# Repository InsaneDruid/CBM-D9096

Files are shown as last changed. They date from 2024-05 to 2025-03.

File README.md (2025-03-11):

# CBM D9096 - a PetSD+ variant
Inspired by the work of Steve J. Gray and his cbmSD-mini, the CBM D9096 is a cost- and feature-reduced version of Nils Eiler's PetSD+ board, designed specifically for headless operation in an external enclosure, connected with a true GPIB cable, similar to a D9060 or D9090.

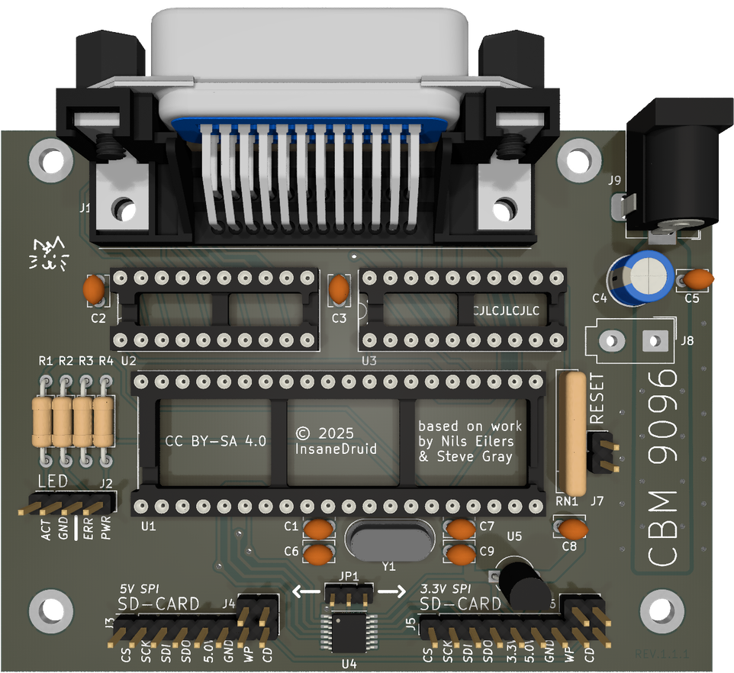
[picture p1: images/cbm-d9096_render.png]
CBM 9096 render


[Schematic](https://github.com/InsaneDruid/cbm-d9096/blob/main/cbm-d9096/cbm-d9096.pdf "Schematic")  

[Bill of Materials](https://htmlpreview.github.io/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 "Bill of Materials")

## The features
A 24-pin Centronics IEEE488/GBIP connector allows the CBM D9096 to be placed anywhere in the IEEE488 chain. This also eliminates the need for a second connector, as the IEEE488 connectors are designed to be stackable.
The SD-Card interface, the status LED and the RESET Button are implemented as pinheaders, so that the main PCB with the GBIB plug and power port can be spaced away from the parts the user needs to interact with, giving flexibility in the design of a case. Additionally, the option to use a Molex Mini Fit Jr Power Plug for connecting to an internal power supply has been implemented.

## The features that got removed
The display with its display controller, the clock, the clock battery, the buttons for interfacing with the display, and the IEC connector have been removed. The circuitry to support SD cards (mainly the 3.3 V power regulator) has also been moved to the readily available card modules. This allows the use of SD and MicroSD modules and the aforementioned flexibility in positioning these modules in a housing.

## The SD card adapters - 1.1.0 adding more options
The board now features two headers to attach readily available SD card and Micro SD card modules.
The one marked *5V SPI SD-CARD* (J3) is operating at 5 volts! The card modules attached here  MUST have appropriate level shifters installed.
Tis applies to nearly all readily available Micro SD card modules, but only some older SD card modules.
Tested and working boards are: *DEBO MICROSD 2* and *C-Control Pro Nr. 197220*
Boards that just use a voltage regulator and some passive resistors do NOT work on this header!

To use the 5V SPI SD-CARD header, JP1 needs to be set to position 2-3 (leftwards)

The one marked *3.3V SPI SD-CARD* (J5) is operating at 3.3 volts using a TXU0304 SPI level shifter and a 3.3V regulator.The card modules attached here don't need (and should *not* have!) their own level shifters.
This applies to nearly all readily available full size SD card modules. Note: this port supplies 3.3V OR 5V to the card module. Select the appropriate pin depending on the card module to connect. 

To use the 3.3V SPI SD-CARD header, JP1 needs to be set to position 1-2 (rightwards)

*Attention!* you CANNOT use two SD card modules at the same time!

## The *card detect* and *write protect* signals
Both SD card headers J3 & J5 have ground pin headers available behind the pins for the card detect ("CD") and write protect ("WP) signals (marked J4 & J6). If the attached card module doesn't provide these signals, for example all Micro SD modules, connect a 2.54mm jumper between the CD and or WP pins of J3/J5 and the associated pin of J4/J6 to permanently tie these signals to ground (permanently enable them).

## The Firmware
Andy Grady has provided a customized [firmware](https://github.com/InsaneDruid/cbm-d9096/blob/main/firmware/cbm-d9096.bin "cbm-d9096.bin") in which the button input is completely deactivated, so that the use of a voltage divider and filtered analog voltage is no longer necessary and with V1.1.0 these supporting parts are omitted. 

### Firmware installation
* Flash the [bootloader](https://github.com/InsaneDruid/cbm-d9096/blob/main/firmware/new-bootloader-for-16-MHz-petSD-plus.hex "new-bootloader-for-16-MHz-petSD-plus.hex") file to the Atmega. 
    * Set the fuse bits to Low: F7, High: D2, Extended: FC
        * low: CKSEL3=low
        * high: SPIEN=0, EESAVE=0, BOOTSZ1=0, BOOTRST=0
        * extended: BODLEVEL1=0, BODLEVEL0=0
* Install the Atmega in the board.
* Copy the [firmware](https://github.com/InsaneDruid/cbm-d9096/blob/main/firmware/cbm-d9096.bin "cbm-d9096.bin") to a FAT16 or FAT32 formatted SD-card.
* Insert the prepared card and turn on the d9096.
* On startup, the bootloader will program the firmware to the Atmega.
    * The file name is not important - the bootloader checks for a hardware tag and version number in the file.
    * During the flash operation the busy LED flickers rapidly.
    * If a valid firmware is not found, the boot loader will flash the error LED for two seconds and try to find a valid file once more.

## The LED options
The board is designed to be configured for a 2 LED or 3 LED setup:

### 2 LED variant
In the 2 LED variant power and error are combined in a *bidirectional* dual-color led (NOT common cathode or common anode!), reminiscent of how the CBM drives did. Activity is shown on a standard LED.

* install a jumper wire in place of R2
* connect a bidirectional LED between pins 3 (error) and 4 (power) of J2
* connect a standard LED between pins 1(activity) and 2 (gnd) of J2

### 3 LED variant
In the 3 LED variant power and error as well as activity are displayed with independent LED.

* don't install R4 (leave open)
* install a 330 Ohm resistor in R1, R2, R3
* connect power LED between pins 4 (power) and 2 (GND) of J2
* connect error LED between pins 3 (error) and 2 (GND) of J2
* connect activity LED between pins 1 (activity) and 2 (GND) of J2

## The printable housing option
To adapt the cheaply available Bahar enclosue 150*140*70mm project box, 3d printable parts are available.

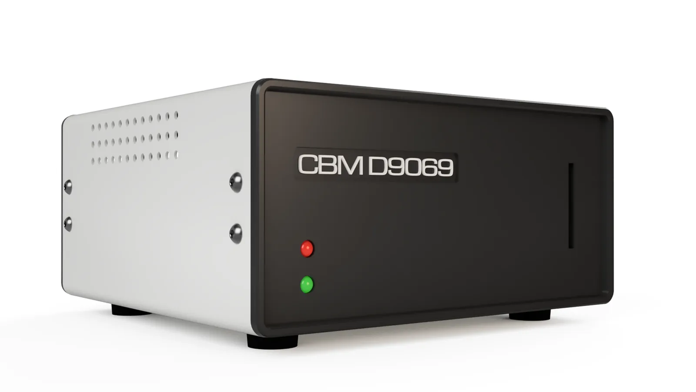
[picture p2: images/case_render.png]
Case render

[Printable parts on printables.com](https://www.printables.com/model/878141-cbm-d9069/ "Printable parts on printables.com")  

## The License
This work is licensed under a Creative Commons Attribution-ShareAlike 4.0 International License.  
See https://creativecommons.org/licenses/by-sa/4.0/.

## The Credits
This work would not have been possible without the work of Nils Eilers and his wonderful PetSD+. In addition, Steve J. Gray had the idea of a similar cost- and feature-reduced version of the PetSD+ when he designed his cbmSD-mini, which uses board-edge connectors and is designed to connect directly to the PETs board and case. This work inspired the CBM D9096.

Special thanks also go to Andy Grady for the customized firmware.

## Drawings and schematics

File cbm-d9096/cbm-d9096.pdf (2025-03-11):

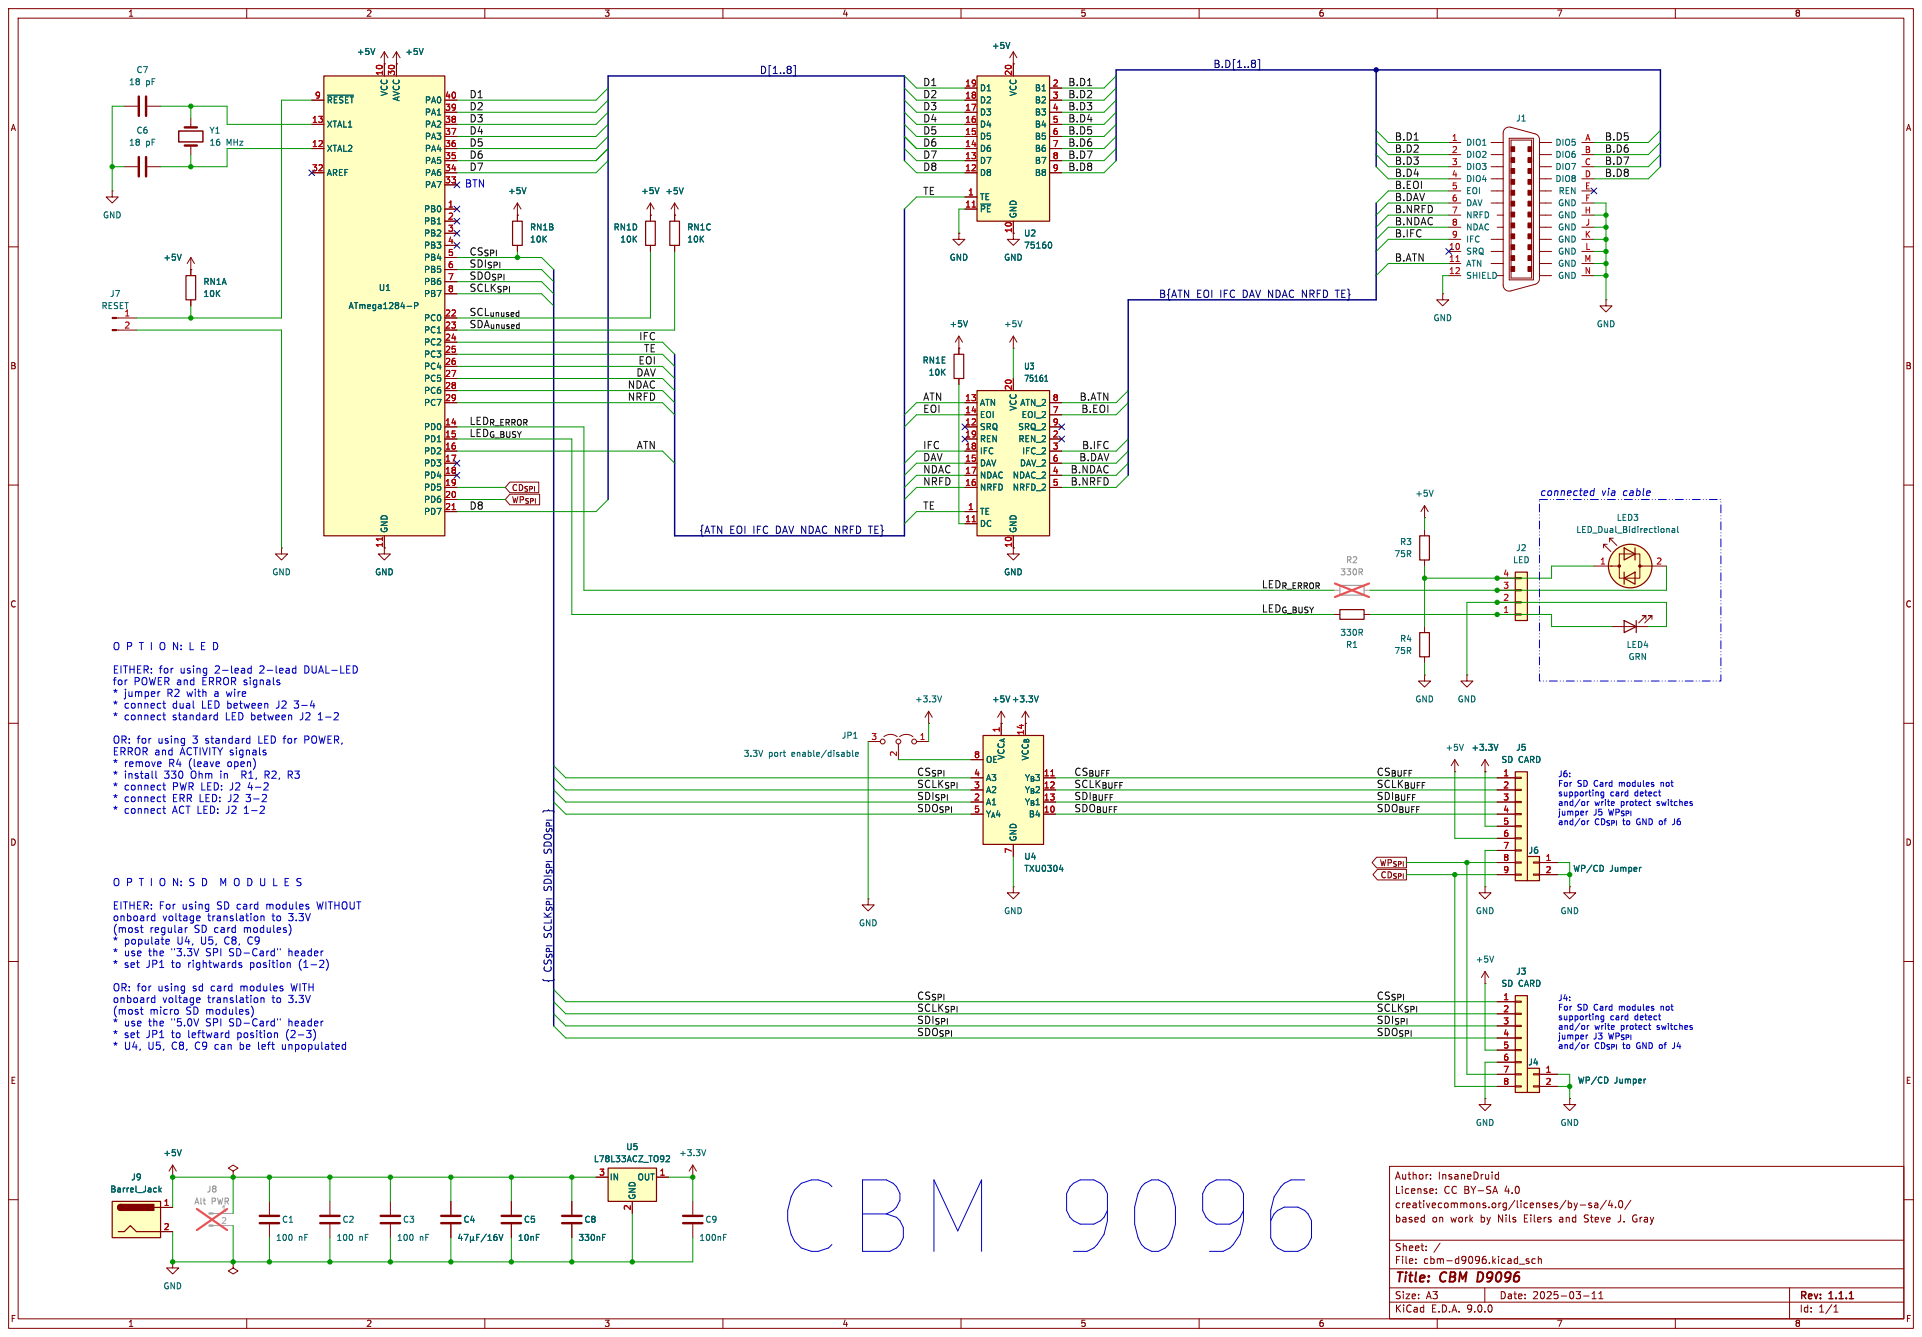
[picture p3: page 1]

DIO1 1 DIO2 2 DIO3 3 DIO4 4 EOI 5 DAV 6 NRFD 7 NDAC 8

DIO8 D
REN E GND F GND H GND J GND K GND L GND M

B{ATN EOI IFC DAV NDAC NRFD TE}

75161 ATN 13 EOI 14 SRQ 12 REN 19
ATN 13 EOI 14 SRQ 12 REN 19

{ATN EOI IFC DAV NDAC NRFD TE}

for POWER and ERROR signals
* jumper R2 with a wire
* connect dual LED between J2 3-4

ERROR and ACTIVITY signals

{ CS_{SPI}SCLK_{SPI}SDI_{SPI}SDO_{SPI} } CS_{SPI}

EITHER: For using SD card modules WITHOUT

OR: for using sd card modules WITH

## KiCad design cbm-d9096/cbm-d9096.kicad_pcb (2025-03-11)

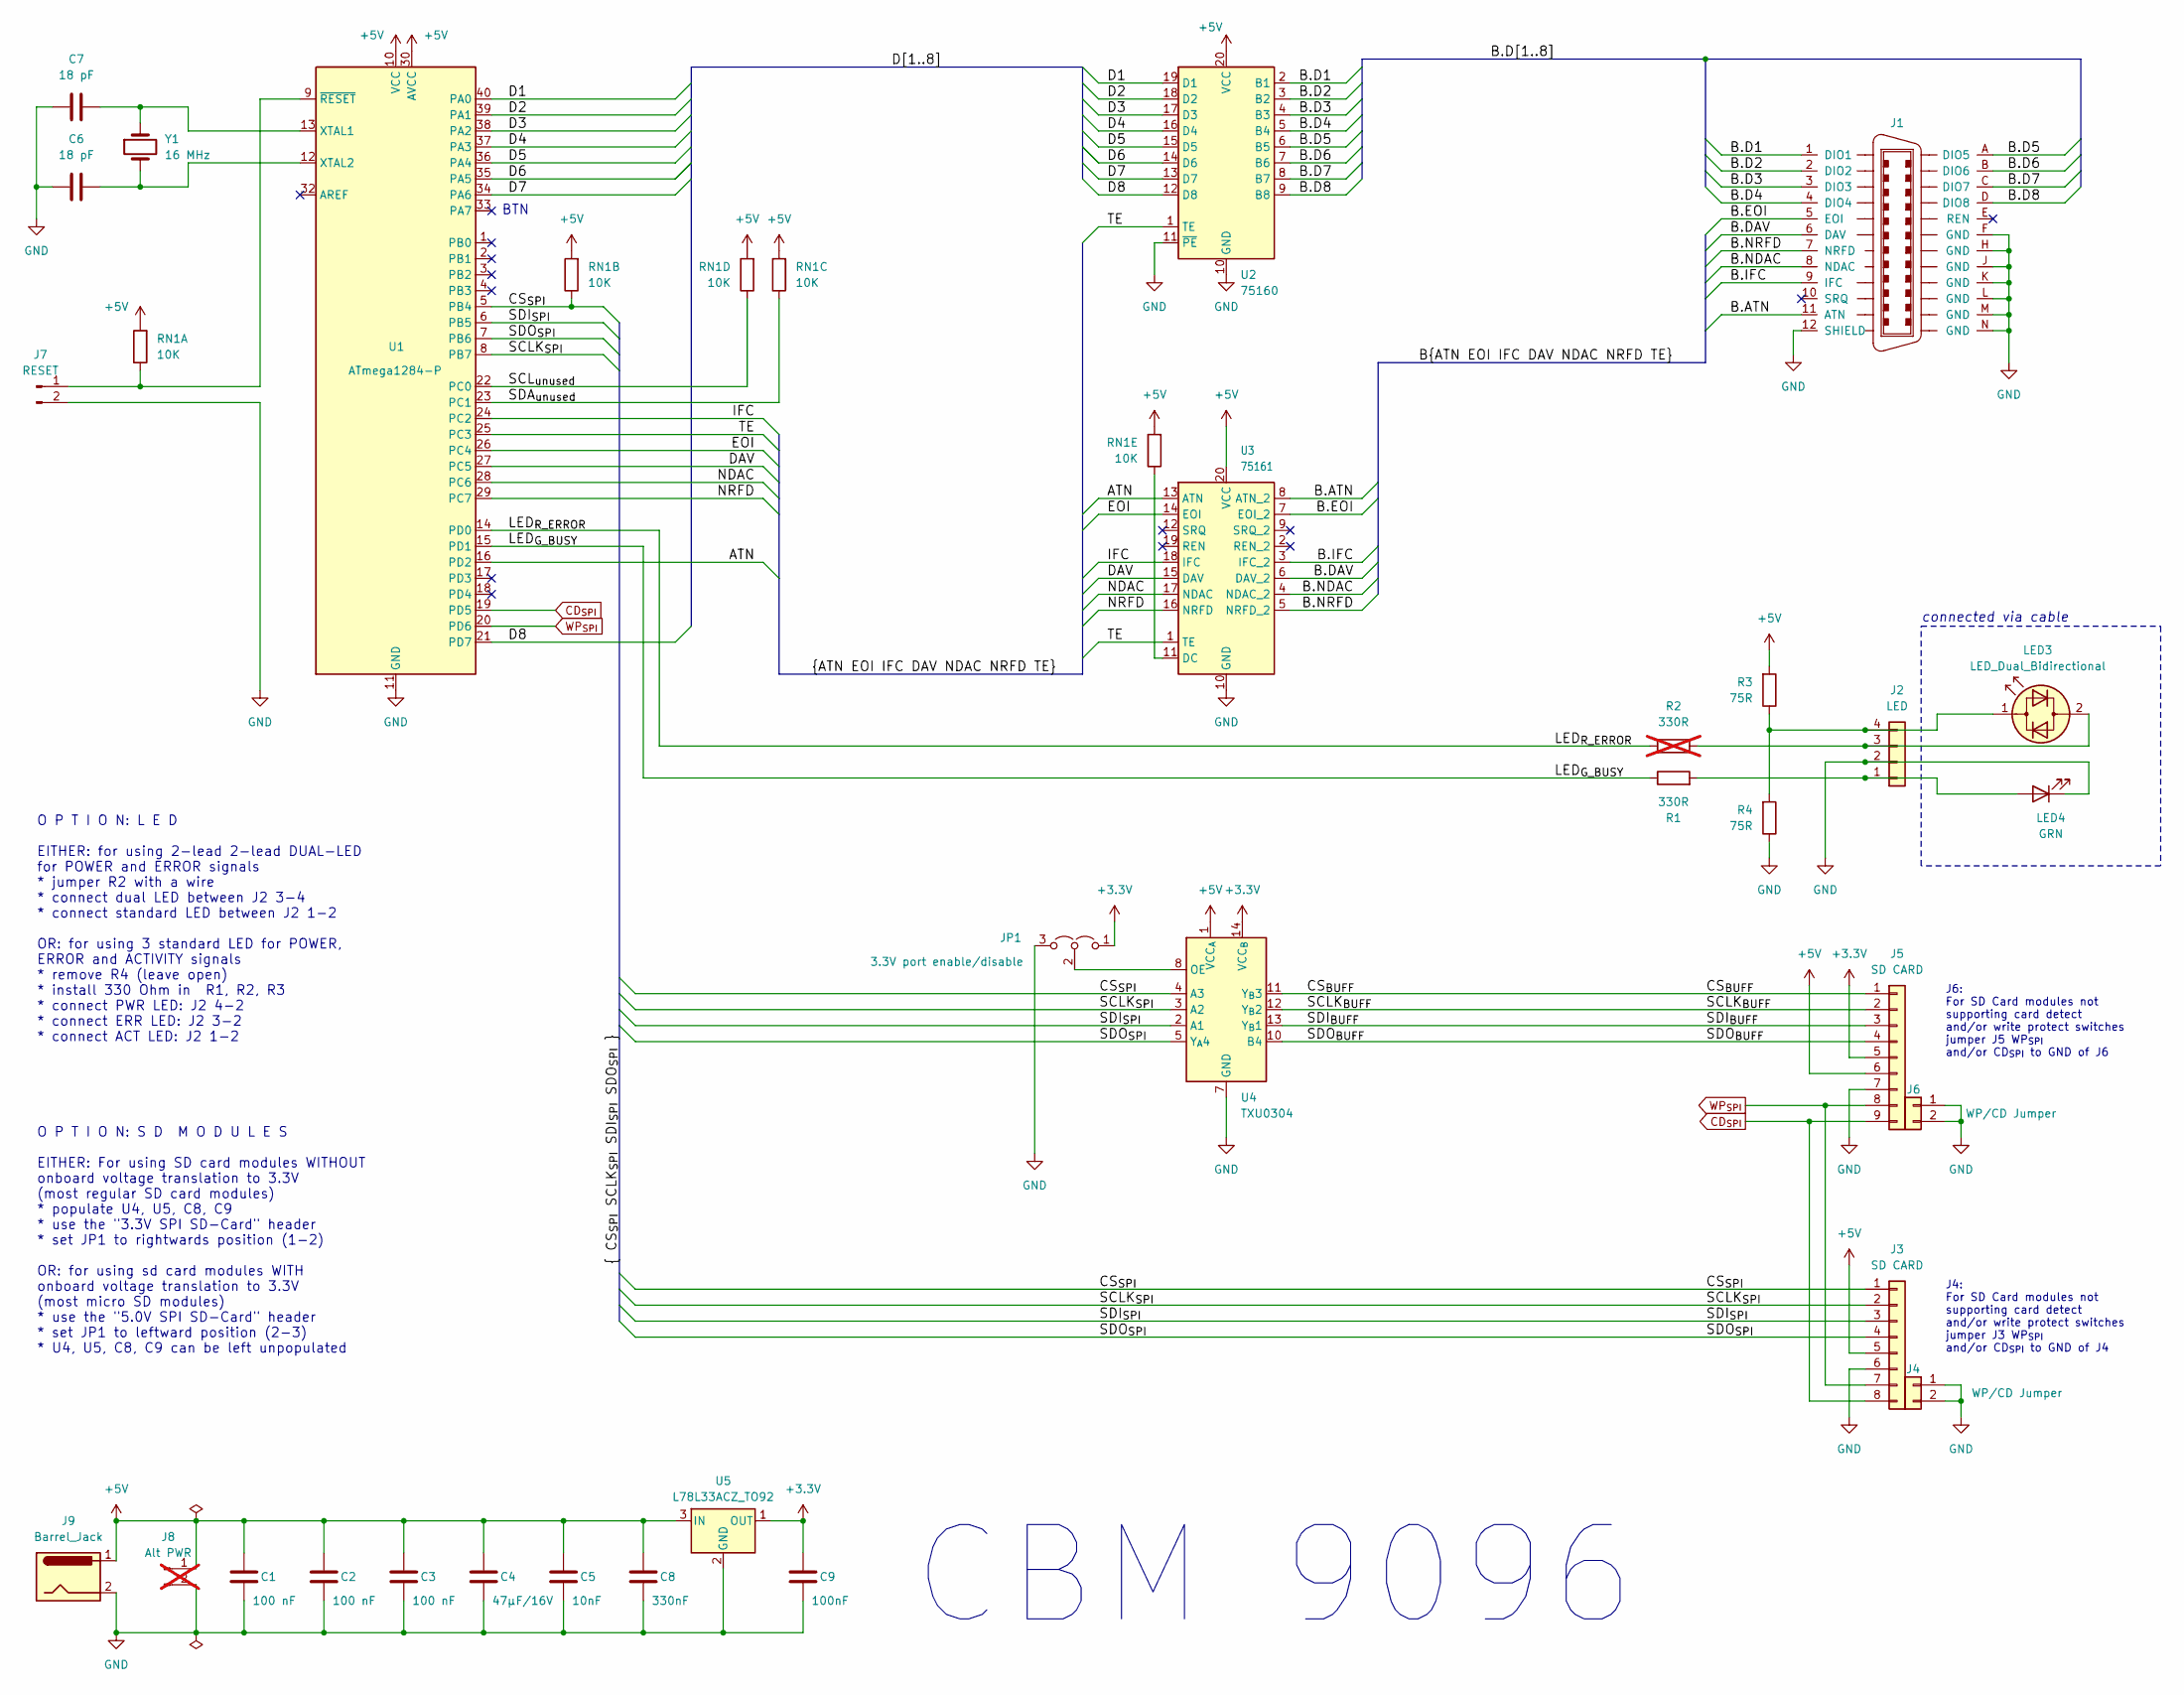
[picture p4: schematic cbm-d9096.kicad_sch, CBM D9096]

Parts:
C1, C2, C3: 100 nF; C_Disc_D3.8mm_W2.6mm_P2.50mm
C4: 47µF/16V; CP_Radial_D6.3mm_P2.50mm
C5: 10nF; C_Disc_D3.8mm_W2.6mm_P2.50mm
C6, C7: 18 pF; C_Disc_D3.8mm_W2.6mm_P2.50mm
C8: 330nF; C_Disc_D3.8mm_W2.6mm_P2.50mm
C9: 100nF; C_Disc_D3.8mm_W2.6mm_P2.50mm
J1: IEEE488 Header; centronix-24-female
J2: LED; PinHeader_1x04_P2.54mm_Vertical
J3: SD CARD; PinHeader_1x08_P2.54mm_Vertical
J4, J6: WP/CD Jumper; PinHeader_1x02_P2.54mm_Vertical
J5: SD CARD; PinHeader_1x09_P2.54mm_Vertical
J7: RESET; PinHeader_1x02_P2.54mm_Vertical
J8: Alt PWR; Molex_Mini-Fit_Jr_5566-02A_2x01_P4.20mm_Vertical; not fitted
J9: Barrel_Jack; BarrelJack_Horizontal
JP1: 3.3V port enable/disable; PinHeader_1x03_P2.00mm_Vertical
LED3: LED_Dual_Bidirectional
LED4: GRN; LED_D3.0mm_Clear
R1: 330R; R_Axial_DIN0207_L6.3mm_D2.5mm_P10.16mm_Horizontal
R2: 330R; R_Axial_DIN0207_L6.3mm_D2.5mm_P10.16mm_Horizontal; not fitted
R3, R4: 75R; R_Axial_DIN0207_L6.3mm_D2.5mm_P10.16mm_Horizontal
RN1: 10K; R_Array_SIP6
U1: ATmega1284-P; DIP-40_W15.24mm_Socket
U2: 75160; DIP-20_W7.62mm_Socket
U3: 75161; DIP-20_W7.62mm_Socket
U4: TXU0304; TSSOP-14_4.4x5mm_P0.65mm
U5: L78L33ACZ_TO92; TO-92L_Inline_Wide
Y1: 16 MHz; Crystal_HC49-4H_Vertical

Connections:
+3.3V: C9.1, J5.5, JP1.1 (A), U4.14 (VCC_{B}), U5.1 (OUT)
+5V: C1.2, C2.2, C3.2, C4.1, C5.1, C8.1, J3.5, J5.6, J8.1, J9.1, R3.2, RN1.1 (R1), U1.10 (VCC), U1.30 (AVCC), U2.20 (VCC), U3.20 (VCC), U4.1 (VCC_{A}), U5.3 (IN)
/ATN: U1.16 (PD2), U3.13 (ATN)
/B.ATN: J1.11 (ATN), U3.8 (ATN_2)
/B.D1: J1.1 (DIO1), U2.2 (B1)
/B.D2: J1.2 (DIO2), U2.3 (B2)
/B.D3: J1.3 (DIO3), U2.4 (B3)
/B.D4: J1.4 (DIO4), U2.5 (B4)
/B.D5: J1.A (DIO5), U2.6 (B5)
/B.D6: J1.B (DIO6), U2.7 (B6)
/B.D7: J1.C (DIO7), U2.8 (B7)
/B.D8: J1.D (DIO8), U2.9 (B8)
/B.DAV: J1.6 (DAV), U3.6 (DAV_2)
/B.EOI: J1.5 (EOI), U3.7 (EOI_2)
/B.IFC: J1.9 (IFC), U3.3 (IFC_2)
/B.NDAC: J1.8 (NDAC), U3.4 (NDAC_2)
/B.NRFD: J1.7 (NRFD), U3.5 (NRFD_2)
/CS_{BUFF}: J5.1, U4.11 (Y_{B}3)
/CS_{SPI}: J3.1, RN1.3 (R2.2), U1.5 (PB4), U4.4 (A3)
/D1: U1.40 (PA0), U2.19 (D1)
/D2: U1.39 (PA1), U2.18 (D2)
/D3: U1.38 (PA2), U2.17 (D3)
/D4: U1.37 (PA3), U2.16 (D4)
/D5: U1.36 (PA4), U2.15 (D5)
/D6: U1.35 (PA5), U2.14 (D6)
/D7: U1.34 (PA6), U2.13 (D7)
/D8: U1.21 (PD7), U2.12 (D8)
/DAV: U1.27 (PC5), U3.15 (DAV)
/EOI: U1.26 (PC4), U3.14 (EOI)
/IFC: U1.24 (PC2), U3.18 (IFC)
/LED_{G_BUSY}: R1.1, U1.15 (PD1)
/LED_{R_ERROR}: R2.1, U1.14 (PD0)
/NDAC: U1.28 (PC6), U3.17 (NDAC)
/NRFD: U1.29 (PC7), U3.16 (NRFD)
/SCLK_{BUFF}: J5.2, U4.12 (Y_{B}2)
/SCLK_{SPI}: J3.2, U1.8 (PB7), U4.3 (A2)
/SCL_{unused}: RN1.5 (R4.2), U1.22 (PC0)
/SDA_{unused}: RN1.4 (R3.2), U1.23 (PC1)
/SDI_{BUFF}: J5.3, U4.13 (Y_{B}1)
/SDI_{SPI}: J3.3, U1.6 (PB5), U4.2 (A1)
/SDO_{BUFF}: J5.4, U4.10 (B4)
/SDO_{SPI}: J3.4, U1.7 (PB6), U4.5 (Y_{A}4)
/TE: U1.25 (PC3), U2.1 (TE), U3.1 (TE)
CD_{SPI}: J3.8, J5.9, U1.19 (PD5)
GND: C1.1, C2.1, C3.1, C4.2, C5.2, C6.1, C7.1, C8.2, C9.2, J1.12 (SHIELD), J1.F (GND), J1.H (GND), J1.J (GND), J1.K (GND), J1.L (GND), J1.M (GND), J1.N (GND), J2.2, J3.6, J4.1, J4.2, J5.7, J6.1, J6.2, J7.2, J8.2, J9.2, JP1.3 (B), LED4.1 (K), R4.1, U1.11 (GND), U1.31 (GND), U2.10 (GND), U2.11 (~PE), U3.10 (GND), U4.7 (GND), U5.2 (GND); also elsewhere on the board
unnamed: J2.1, LED4.2 (A), R1.2
unnamed: J2.3, LED3.2 (AK), R2.2
unnamed: J2.4, LED3.1 (KA), R3.1, R4.2
unnamed: J7.1, RN1.2 (R1.2), U1.9 (~RESET)
unnamed: JP1.2 (C), U4.8 (OE)
unnamed: RN1.6 (R5.2), U3.11 (DC)
unnamed: C7.2, U1.13 (XTAL1), Y1.1
unnamed: C6.2, U1.12 (XTAL2), Y1.2
WP_{SPI}: J3.7, J5.8, U1.20 (PD6)

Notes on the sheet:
connected via cable
J4: For SD Card modules not supporting card detect and/or write protect switches jumper J3 WP_{SPI} and/or CD_{SPI} to GND of J4
J6: For SD Card modules not supporting card detect and/or write protect switches jumper J5 WP_{SPI} and/or CD_{SPI} to GND of J6
O P T I O N: L E D EITHER: for using 2-lead 2-lead DUAL-LED for POWER and ERROR signals * jumper R2 with a wire * connect dual LED between J2 3-4 * connect standard LED between J2 1-2 OR: for using 3 standard LED for POWER, ERROR and ACTIVITY signals * remove R4 (leave open) * install 330 Ohm in R1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
BTN
O P T I O N: S D M O D U L E S EITHER: For using SD card modules WITHOUT onboard voltage translation to 3.3V (most regular SD card modules) * populate U4, U5, C8, C9 * use the "3.3V SPI SD-Card" header * set JP1 to rightwards position (1-2) OR: for using sd card modules WITH onboard voltage transla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
CBM 9096

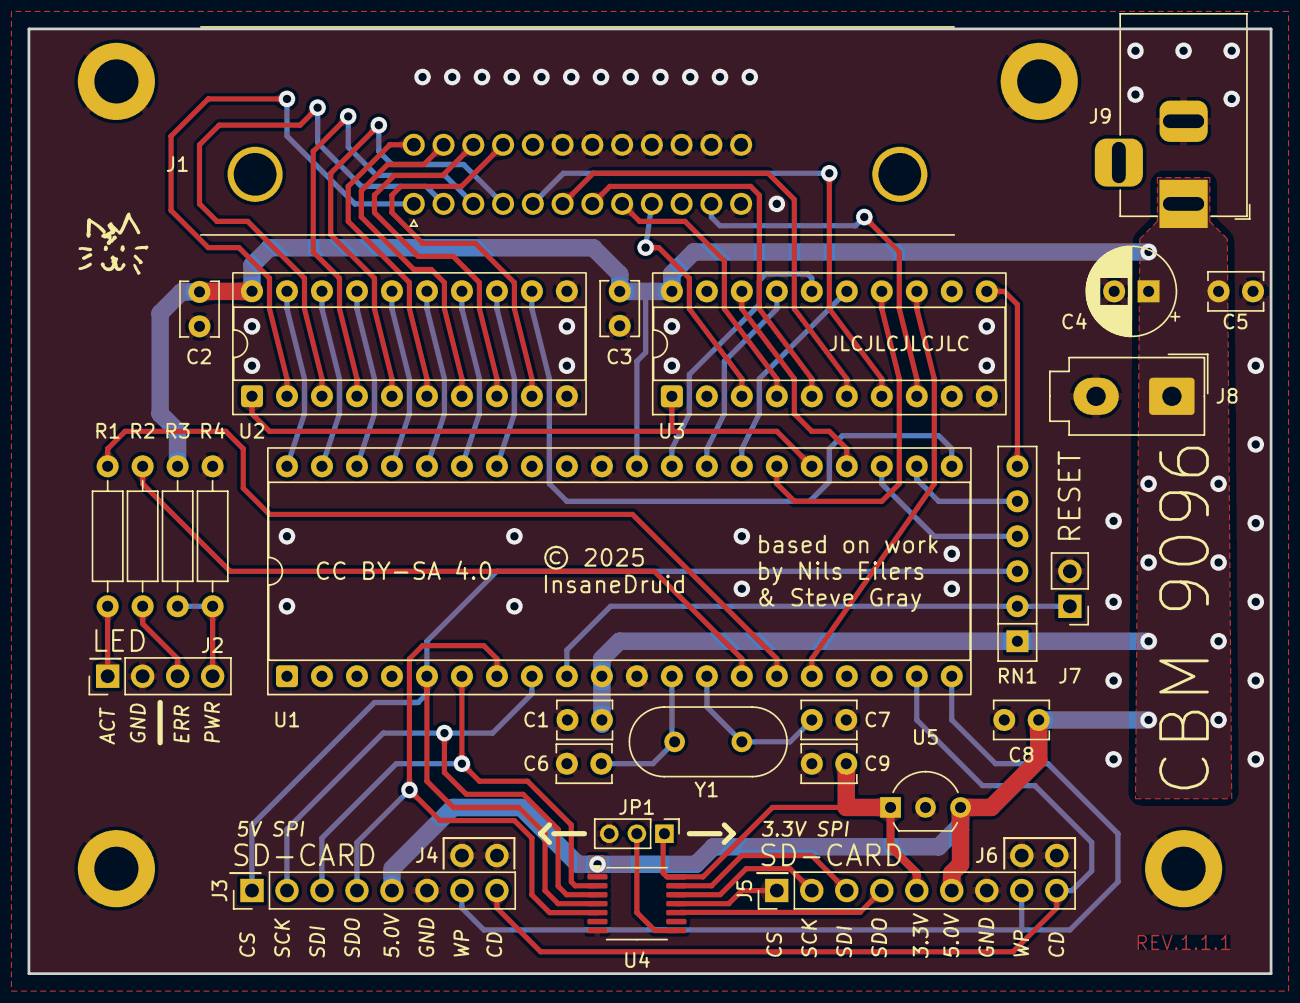
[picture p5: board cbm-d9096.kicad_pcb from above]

Board: 2 copper layers, 90.2 x 68.6 mm, 34 parts (0 on the bottom side), 54 nets.

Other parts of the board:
MH1, MH2, MH3, MH4: MountingHole_3.2mm_M3_DIN965_Pad

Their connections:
GND: MH1.1, MH2.1, MH3.1, MH4.1; also elsewhere on the board

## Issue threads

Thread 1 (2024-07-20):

AMTEL1284 Firmware

SwitchGB, 2024-07-20:
I cant see the firmware for the AMTEL1284 in the git download.

InsaneDruid, 2024-07-20:
That's because it uses the official firmware of the petsd+ (the sd2iec bootloader and the nodiskemu firmware). So its the same as in any other PetSD+ implementation.

A good explanation is found here: http://www.primrosebank.net/computers/pet/projects/pet_petsd_fw.htm

Basically, you flash the *New Bootloader for 16Mhz petSD+* (found in the link above) to the ATMEL. Set the Fuses to

### Fuse Low Byte: F7
CKSEL3=0

### Fuse High Byte: D2
SPIEN
EESAVE=0
BOOTSZ1=0
BOOTRST=0

### Extended Fuse Byte: FC
BODLEVEL1=0
BODLEVEL0=0

Then get the NODISKEMU firmware (i recommend the 2017-10-05 release as it hasn't the cold boot bug and all the features needed) from https://petsd.net/nightlies.php, put the file on a SD card (needs to be named "petSD+.bin") and during the first boot the bootloader will flash the firmware.

SwitchGB, 2024-07-20:
That helped a lot, I seem to now have firmware loading, at least there is a lot of flashing of the activity light while the error light is on then it all stops and on the next boot just a couple of flashes. I cant yet get anything from the drive but will test my IEEE488 port next.

InsaneDruid, 2024-07-21:
I added a readme section about SD card interface board compatibility. I had massive issues with a board that just used resistors and a voltage regulator for the card itself (ARD MODULE SD Arduino - SD-Karten-Modul from reichelt.de).
*DEBO MICROSD 2* and *C-Control Pro Nr. 197220* (Micro SD and standard SD size) are tested to be fully working. Both use real level shifters to interface all the signals and are as cheap as the ones using passives.

SwitchGB, 2024-07-23:
Ok some progress I am sure the firmware is loading ok, from a fresh bootloader with no SDCard a 'directory' command  returns '?device not present error'
Once the SD Card is installed and the bootloader has finished installing the firmware and rebooted the 'directory' command  returns 'ready'

However I can not get a directory listing or see any programs copied to the SD Card.

loading returns '?file not found error'

So I was wondering about SD Card compatibility but thinking that the firmware has loaded ok makes me think the application is reading the card ok ?

I have a Kingston 32GB MicroSD Class 10 Card (795545125553) formatted to FAT32.

Any Ideas ?

Here is a picture of my progress so far :)
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

InsaneDruid, 2024-07-23:
CD and WP (disk change and write protect) need to be either connected to a card interface that support them or need to be grounded. Thats where J3 (both pins are GND) is for: if you install pin headers to J3 and the 2 last pins pf J2 you can put on some jumpers - or just use solder to bridge over.

SwitchGB, 2024-07-23:
Yes I have them grounded see here:
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

SwitchGB, 2024-07-23:
Do you have a list of MicroSD Cards that are known working ?

InsaneDruid, 2024-07-23:
SanDisk Ultra microSDHC do work, and some no names, too.

Have you tried device numbers other then 8?
like catalog onu 9/10/11/12?

you can change the device number laterwith the U0 command
https://github.com/nils-eilers/NODISKEMU?tab=readme-ov-file#u0

and then save the config with the XW command.

For 3 LED you should remove R6 btw, and what value are R5 and R6? Really 6.5 Ohms? (blue green black silver brown)?

SwitchGB, 2024-07-24:
Whoop :) it works :)

it was the device number - cAu11 worked and retuned a listing and I can run a program.
Its on U11 - Not sure why its defaulted to that need to investigate.

Yes the resistors are correct, probably the light they came in a kit on Amazon 1% but you are right they multiplier looks more silver than gold.

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

SwitchGB, 2024-07-24:
Excellent now working as expected on 8  :) I must thank you for your help would have induced a lot more frustration if I worked it out on my own :)

So the ONLY issue I now have is it takes 3-4 reboots from cold before the activity light goes off and the board functions, have you came across this - I have not tried later firmware only the one you recommended :)

InsaneDruid, 2024-07-25:
This is a known problem of all PetSD+, but actually one that happens on the firmware builds AFTER the 2017-10-05 build: http://www.primrosebank.net/computers/pet/projects/pet_petsd_fw_revs.htm

Unfortunately, the dev abandoned the firmware and the issue never really was found, or fixed.

What I found though is that is better to switch the low voltage supply and not the power to a PSU powering the board.

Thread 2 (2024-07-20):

R4 Missing from BOM

SwitchGB, 2024-07-20:
R4 is missing off the BOM :)

InsaneDruid, 2024-07-20:
That's by design as it needs to be a jumper when using bidirectional dual LED for PWR/ERROR (like on the disk drives). Thus its marked _don't install_ in the schematics. It his, however, referenced as "R2" in the Text describing the setup for 3 discrete LED :)

InsaneDruid, 2024-07-21:
fixed schematics text and added readme sections

Closed 2024-07-21.

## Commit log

2024-07-21 - fixed schematics text referring to R4 as R2
    [cbm-d9096.kicad_sch]
2024-07-21 Update README.md
    - added readme section about LED variants
    - added readme section about SD card interface compatibility (required level shifters)
2024-10-30 Custom Firmware
    Added custom firmware by Andry Gray omitting the button checks in firmware, allowing for the removal of the removal of the resistor divider formed by resistors R1 and R2
    [cbm-d9096.kicad_sch]
2024-10-30 RN1 Description fix
    RN1 was described as 6x10K, changed to the correct 5*6K
    [cbm-d9096.kicad_pcb, cbm-d9096.kicad_sch]
2025-02-22 1.1.0
    - added a second SD port incorporating a 3.3V level shifter
    - removed now obsolete parts for key input
    - moved kicad project into own subfolder to allow further addons
    - fixed some..typos?!, niiice ;)
    [cbm-d9096.kicad_pcb, cbm-d9096.kicad_sch]
2025-03-08 fixed CD/WP silkscreen on second port
    [cbm-d9096.kicad_pcb]
2025-03-11 added jumper to quickly enable/disable the level shifter
    [cbm-d9096.kicad_pcb, cbm-d9096.kicad_sch]

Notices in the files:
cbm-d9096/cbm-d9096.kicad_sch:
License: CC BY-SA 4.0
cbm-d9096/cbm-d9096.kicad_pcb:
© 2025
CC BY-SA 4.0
